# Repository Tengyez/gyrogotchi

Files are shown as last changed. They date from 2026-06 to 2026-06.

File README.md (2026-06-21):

# Gyrogotchi

A tamagotchi that reacts when you flip them in a 4x4 cube keychain using xiao esp32 s3 and mpu6050.

## Description

This is a tamagotchi keychain that introduce another way to interact with the chracter using a gyroscope to be able to tilt the character to triger different animation and around like having a small hamster in a keychain. I wanted to create this because I got inspired by those old 2000 toys where there's innovation and new idea and everythings seems fascinating. My goal here is to make a keychain personalized for me and also double as a nametag I did this by adding a secret code that when I hold a button for 1.5 seccond my credit and name would pop up.

## Getting Started

### Usage

* charge from the usbc port
* press the capacitive touch sensor embeded at the left side 
* shake to wake the character up from sleeping and tilt or flip to trigger different animation
* hold 1.5 seccond to trigger my personalized credit
* connect to gyrogotchi captive portal acess point to broad cast message to the screen and synce time

### Assembling

* Print out the 3d parts (body, cap, minicap, cover) please use the 3mf file I beg you
* place the 500mah lipo batterpack in horizontally
* slide down the cover 3d piece to lock the lipo in place
* put the xiao esp32 s3 in make sure it fits into the usbc slot
* cover the xiao esp32 with the 3d printed minicap
* then place in the mpu6050 on to the two poles above
* then put in the oled screen facing the plastic
* add in the pin to the capacitive touch then solder than cut off the excesspart this need to be flushed to the plastic
* then put in the capacitive touch module make sure the touch side is facing the plastic
* then slide in the vibrating module
* the wire them all up and splice some wire (follow the wiring guide below)
* finally slide in the 3d printed cap

### Wiring
* MPU-6050 to Xiao esp32 S3
* VCC | 3V3
* GND | GND 
* SCL | D5 
* SDA | D4 
* OLED to Xiao esp32 S3
* VCC | 3V3 
* GND | GND 
* SCL | D5 
* SDA | D4 
* Touch (TTP223B) to Xiao esp32 S3
* VCC | 3V3 
* GND | GND 
* SIG | D1 
* Vibrator to Xiao esp32 S3
* Plus | D2
* Negative | GND
* LiPo to Xiao esp32 S3
* Plus | BAT+ 
* Negative | BAT- 
* Splice all 3.3v together and add solder and a electrical tape!!!
* Splice all GND together and add solder and a electrical tape!!!
* Refers to the schematic down below for more indepth guide.

### Firmware

* The code is in C++ made for Xiao ESP-32 S3
* The library version might change over time, please recheck it again.
* feel free to edit and change the credit however you want!
* Check out the [Firmware](firmware/Firmware.ino)
## Materials

This is the BOM of the entire project, just buy the normal one not the pcb version and just use jumper wire with minimal soldering required except for slicing GND together.
```
* Xiao esp32 S3                      1pcs.        20usd
* MPU-6050                           1pcs.        3usd
* 0.96" Inch I2C IIC OLED            1pcs.        3usd
* Touch (TTP223B)                    1pcs.        1usd
* Vibration Motor Module (Catalex)   1pcs.        1usd
* Female Jumper Wires                20pcs.       1usd
* Male Jumper wires                  15pcs.       50cent
* Electrical tape                    1roll        -
* Lipo Battery                       500mah       10usd
* PLA 3d printing/time               ≈25g ≈50min  -
Total cost: 39.5usd
```

## Assembled Pictures


## Rendered Pictures



## Captive Portal interface


## Schematic 


# Zine Poster
GYRO-GOTCHI

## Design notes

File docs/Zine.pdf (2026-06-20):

## GYRO-GOTCHI

# by Teng 15y Play it!

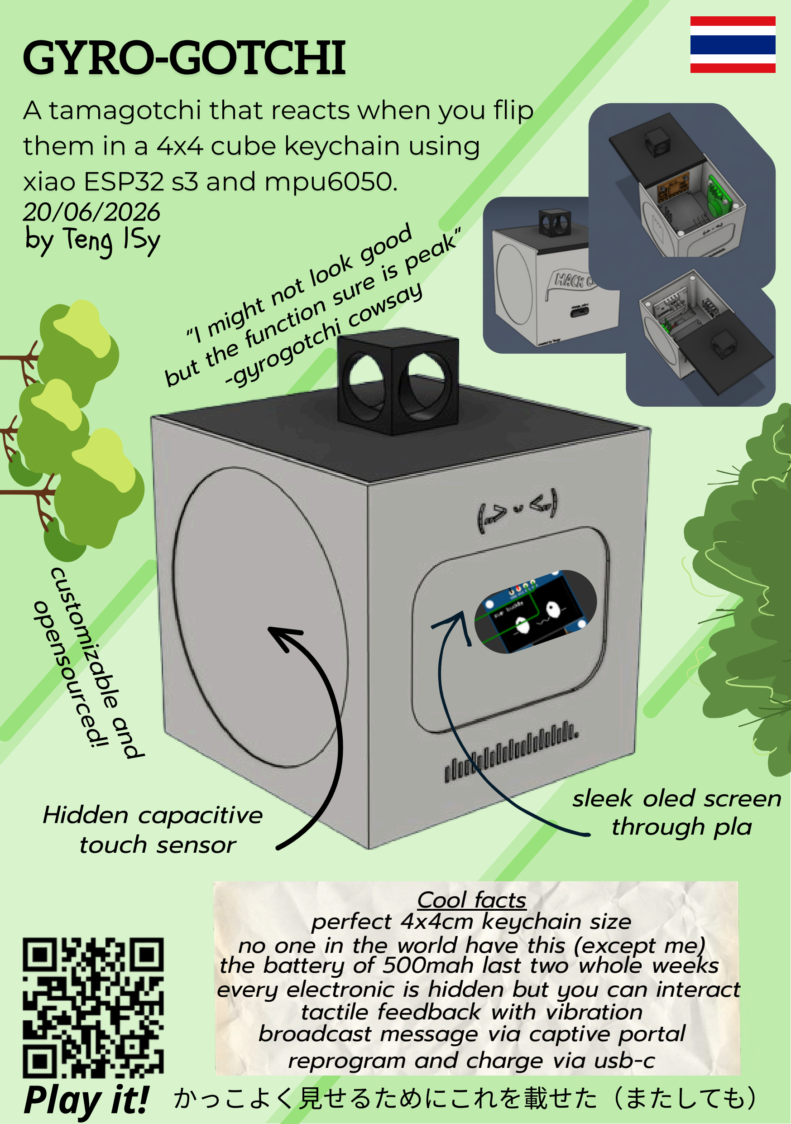
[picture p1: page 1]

A tamagotchi that reacts when you flip them in a 4x4 cube keychain using xiao ESP32 s3 and mpu6050.

A tamagotchi that reacts when you ip them in a 4x4 cube keychain using xiao ESP32 s3 and mpu6050. 20/06/2026

Hidden capacitive
touch sensor

sleek oled screen
through pla

“I might not look good
but the function sure is peak” -gyrogotchi cowsay
かっこよく | 見せるためにこれを載せた（またしても）

perfect 4x4cm keychain size
no one in the world have this (except me)
the battery of 500mah last two whole weeks every electronic is hidden but you can interact tactile feedback with vibration broadcast message via captive portal reprogram and charge via usb-c

Cool facts

customizable

and

opensourced!

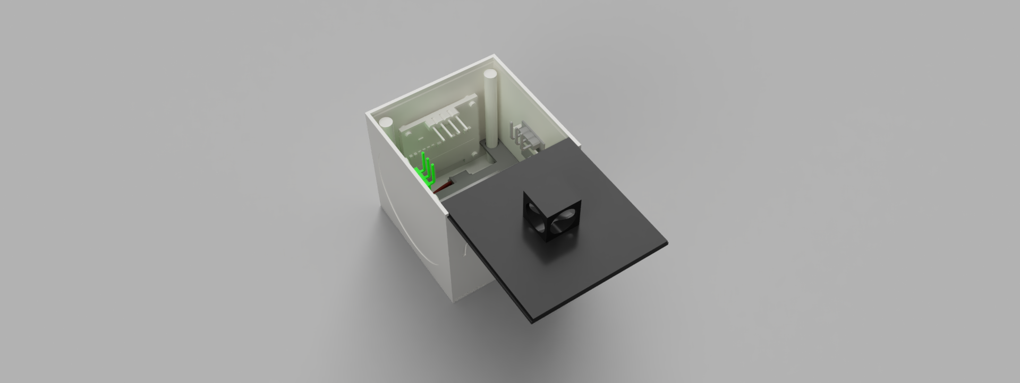
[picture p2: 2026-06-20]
docs/model_pictures/rendered back open.png

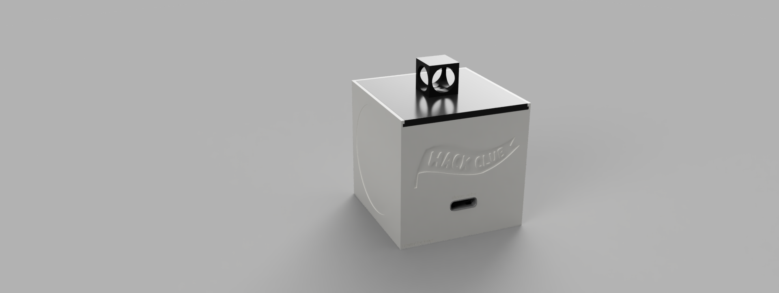
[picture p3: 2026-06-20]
docs/model_pictures/rendered back closed.PNG

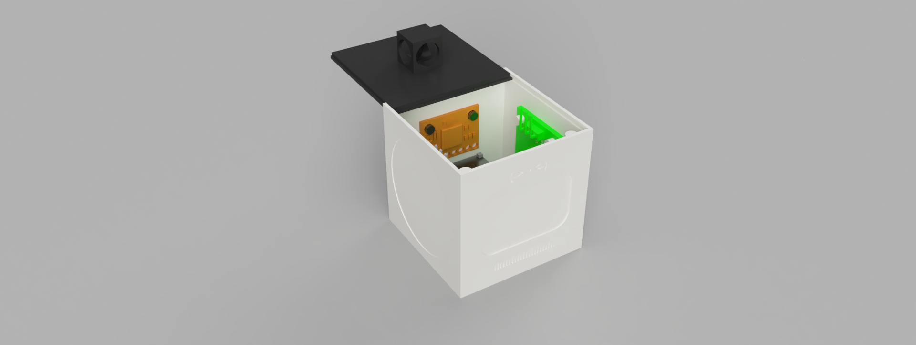
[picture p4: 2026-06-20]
docs/model_pictures/render front open.PNG

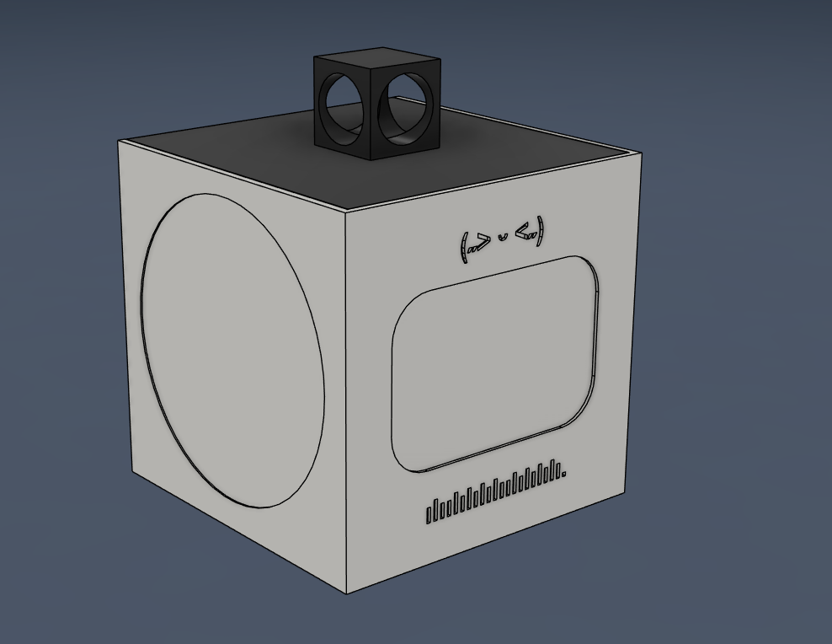
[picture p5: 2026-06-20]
docs/model_pictures/closed.png

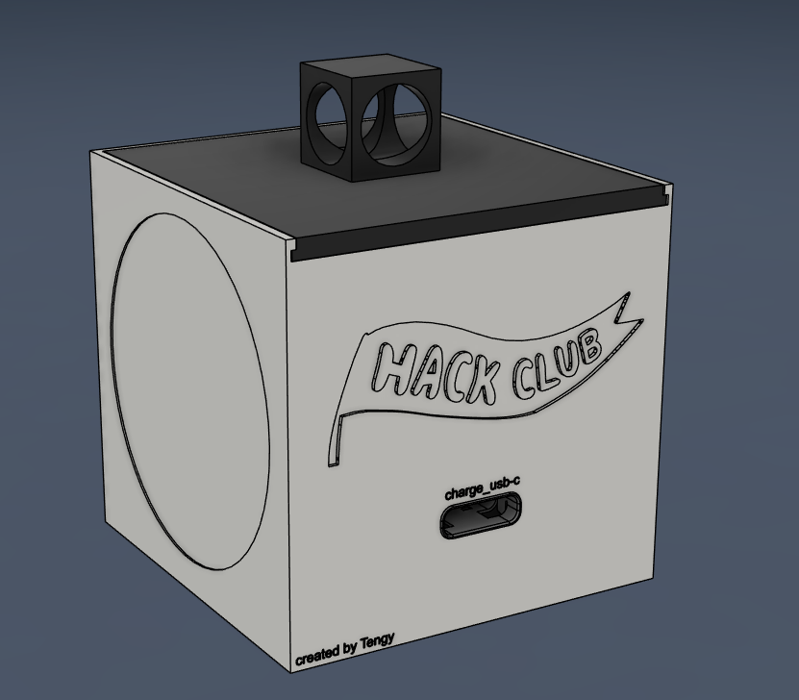
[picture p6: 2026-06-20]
docs/model_pictures/back.png

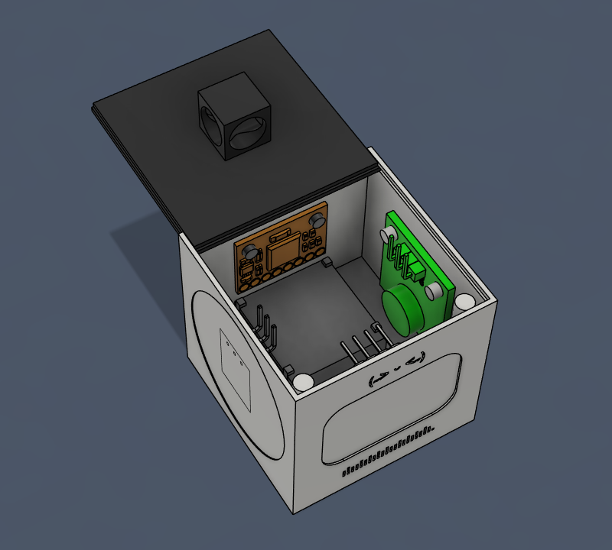
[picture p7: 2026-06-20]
docs/model_pictures/front mini open.png

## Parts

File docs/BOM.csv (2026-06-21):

Components | quantity | comments | link | cost
Xiao esp32 s3 | 1pcs | The small one with no pins | https://www.ortech-online.com/product/5609/xiao-esp32-s3-seeed-studio-%E0%B8%9A%E0%B8%AD%E0%B8%A3%E0%B9%8C%E0%B8%94-esp32-s3-%E0%B8%82%E0%B8%99%E0%B8%B2%E0%B8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 | 20usd
Mpu-6050 | 1pcs | no pins | https://www.ortech-online.com/product/6414/mpu-6050-n-%E0%B9%81%E0%B8%9A%E0%B8%9A%E0%B9%84%E0%B8%A1%E0%B9%88%E0%B8%9A%E0%B8%B1%E0%B8%94%E0%B8%81%E0%B8%A3%E0%B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 | 3usd
0.96" Inch I2C IIC OLED | 1pcs | blue one | https://www.ortech-online.com/product/623/1%E0%B8%8A%E0%B8%B4%E0%B9%89%E0%B8%99-aa412-%E0%B8%AB%E0%B8%99%E0%B9%89%E0%B8%B2%E0%B8%88%E0%B8%AD-%E0%B8%88%E0%B8%A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 | 3usd
touch ttp223b | 1pcs | - | https://www.arduino4pro.com/product/1234/ttp223b-digital-touch-sensor | 1usd
Vibration motor module | 1pcs | catalex | https://www.allnewstep.com/product/1346/%E0%B9%82%E0%B8%A1%E0%B8%94%E0%B8%B9%E0%B8%A5%E0%B8%A1%E0%B8%AD%E0%B9%80%E0%B8%95%E0%B8%AD%E0%B8%A3%E0%B9%8C%E0%B8%AA%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 | 1usd
female jumper wires | 20pcs | any | - | 1usd
male jumper wires | 15pcs | any | - | 50cent
electrical tape | 1roll | any | - | -
lipo battery | 1pcs | 500mah | https://shopee.co.th/%E0%B9%81%E0%B8%9A%E0%B8%95%E0%B9%80%E0%B8%95%E0%B8%AD%E0%B8%A3%E0%B8%B5%E0%B9%88-500mAh-403040-3.7v-Battery-Lipo-polymer-lithium-recharg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 | 10usd
pla | 25g | 50min | - | -
Total cost | 39.5usd | - | - | -

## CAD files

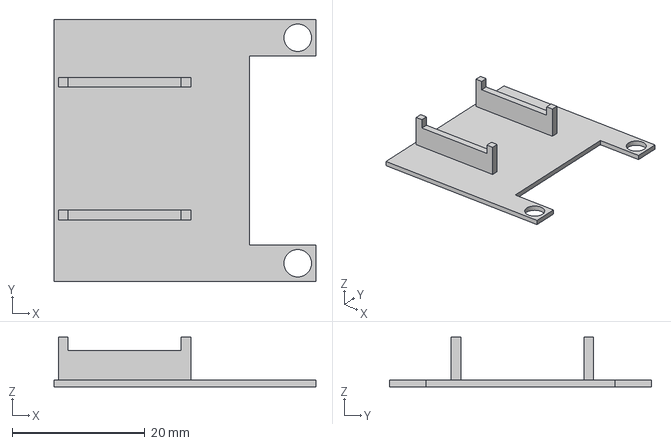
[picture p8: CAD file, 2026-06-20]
3d_print/cover.3mf
39.5 x 39.5 x 7.47 mm

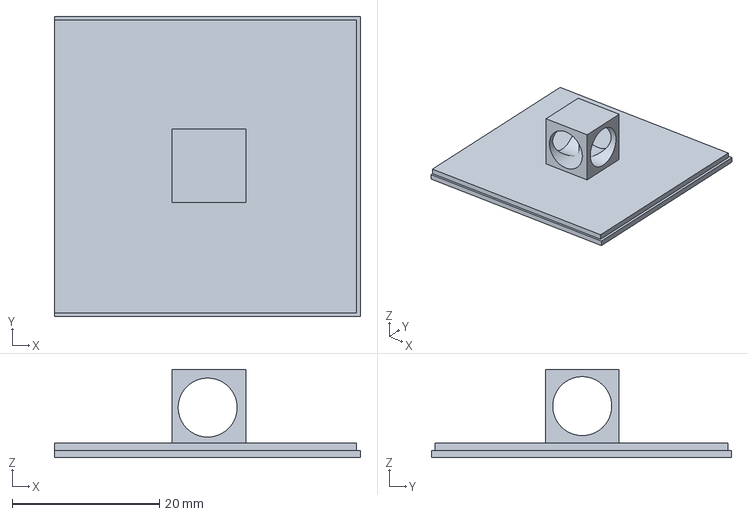
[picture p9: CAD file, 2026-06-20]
3d_print/cap.3mf
41.5 x 40.7 x 12.0 mm

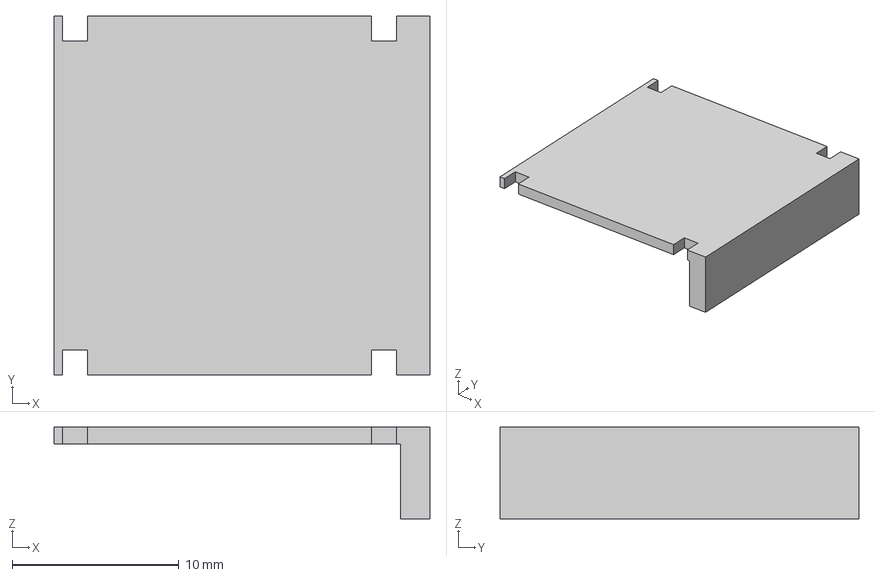
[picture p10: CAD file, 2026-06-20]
3d_print/minicap.3mf
22.5 x 21.5 x 5.50 mm

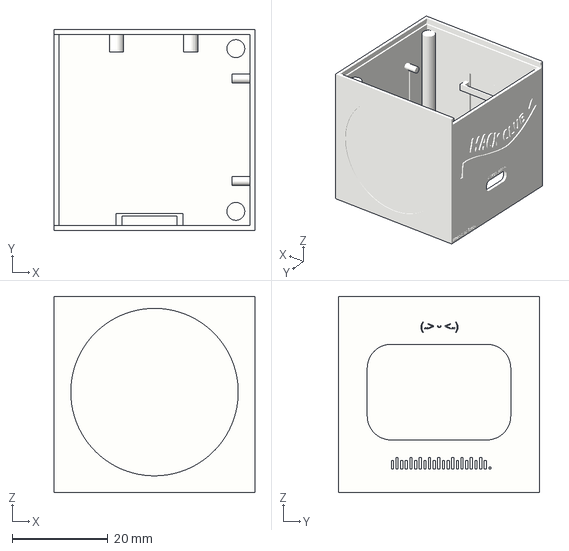
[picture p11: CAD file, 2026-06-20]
3d_print/body.3mf
42.0 x 42.0 x 41.0 mm

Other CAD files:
3d_print/body.stl
3d_print/cap.stl
3d_print/cover.stl
3d_print/minicap.stl

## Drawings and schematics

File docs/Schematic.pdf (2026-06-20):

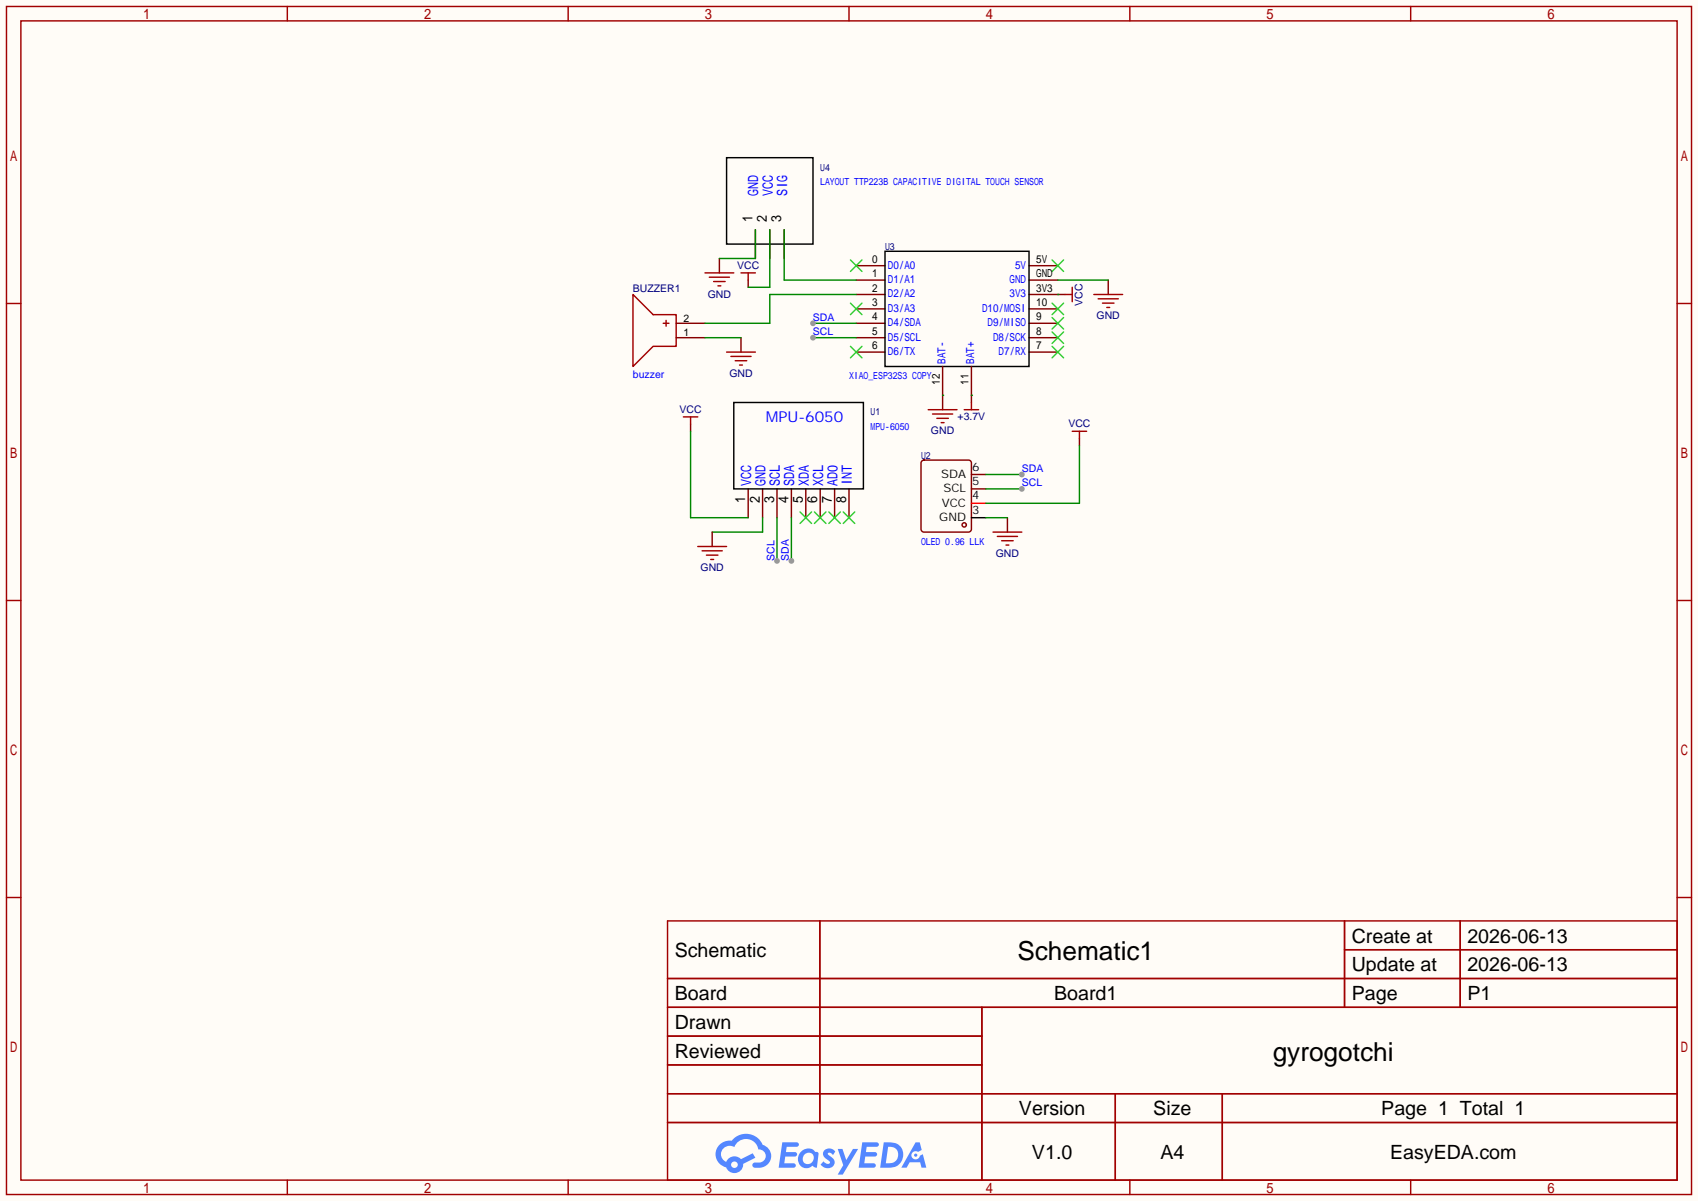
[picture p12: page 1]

LAYOUT TTP223B CAPACITIVE DIGITAL TOUCH SENSOR

Schematic | Schematic1 | Create at | 2026-06-13

Update at | 2026-06-13

Board | Board1 | Page | P1
Drawn | | gyrogotchi
Reviewed

Version | Size | Page 1 Total 1
V1.0 | A4 | EasyEDA.com

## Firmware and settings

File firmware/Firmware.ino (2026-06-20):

#include <Wire.h>
#include <Adafruit_GFX.h>
#include <Adafruit_SSD1306.h>
#include <Adafruit_MPU6050.h>
#include <Adafruit_Sensor.h>
#include <WiFi.h>
#include <DNSServer.h>
#include <WebServer.h>
#include <time.h>

#define TOUCH_PIN      1
#define VIBRATOR_PIN   2

#define SCREEN_WIDTH 128
#define SCREEN_HEIGHT 64
#define OLED_RESET    -1

Adafruit_SSD1306 display(SCREEN_WIDTH, SCREEN_HEIGHT, &Wire, OLED_RESET);
Adafruit_MPU6050 mpu;

WebServer server(80);
DNSServer dnsServer;
const byte DNS_PORT = 53;

int blink_counter = 0;
int zzz_counter = 0;
bool is_sleeping = true; 

unsigned long last_interaction_time = 0;
const unsigned long SLEEP_TIMEOUT = 45000;

unsigned long touch_start_time = 0;
bool touch_was_active = false;
bool showing_credits = false;

String cowsay_text = "";
unsigned long custom_text_display_expiry = 0;

RTC_DATA_ATTR bool has_time_synced = false;
RTC_DATA_ATTR unsigned long rtc_sync_time = 0;
RTC_DATA_ATTR unsigned long rtc_sync_millis = 0;

bool wifi_active = false;
unsigned long wifi_start_millis = 0;
const unsigned long WIFI_PORTAL_TIMEOUT = 60000;

int getBatteryPercentage() {
  pinMode(14, OUTPUT);
  digitalWrite(14, LOW);
  
  int raw = analogRead(10);
  float voltage = (raw / 4096.0) * 3.3 * 2.0; 

  int percent = map(voltage * 100, 330, 420, 0, 100);
  return constrain(percent, 0, 100);
}

String getOrientationString(float x, float y) {
  if (y < -4.0) return "Upside Down";
  if (x < -4.0) return "Tilting Left";
  if (x > 4.0)  return "Tilting Right";
  return "Flat / Centered";
}

unsigned long getCalculatedEpoch() {
  if (!has_time_synced) return 0;
  return rtc_sync_time + ((millis() - rtc_sync_millis) / 1000);
}

void goToDeepSleep() {
  if (wifi_active) {
    WiFi.softAPdisconnect(true);
    WiFi.mode(WIFI_OFF);
  }
  display.clearDisplay();
  display.display();
  digitalWrite(VIBRATOR_PIN, LOW);
  
  esp_deep_sleep_enable_ext0_wakeup((gpio_num_t)TOUCH_PIN, 1);
  esp_deep_sleep_start();
}

void syncTimeFromParam() {
  if (server.hasArg("epoch")) {
    long long epoch = atoll(server.arg("epoch").c_str());
    struct timeval tv;
    tv.tv_sec = epoch;
    tv.tv_usec = 0;
    settimeofday(&tv, NULL);
    rtc_sync_time = epoch;
    rtc_sync_millis = millis();
    has_time_synced = true;
  }
}

void handleRoot() {
  last_interaction_time = millis();
  syncTimeFromParam();
  
  sensors_event_t a, g, t;
  mpu.getEvent(&a, &g, &t);
  
  String html = "<!DOCTYPE html><html><head><meta name='viewport' content='width=device-width, initial-scale=1.0'>";
  html += "<style>body{background:#0f141c;color:#00ffcc;font-family:monospace;text-align:center;padding:20px;}";
  html += ".card{background:#161f2e;border:2px solid #00ffcc;border-radius:8px;padding:15px;margin:15px auto;max-width:400px;box-shadow:0 4px 10px rgba(0,255,204,0.2);}";
  html += "input[type='text']{width:80%;padding:10px;background:#0f141c;border:1px solid #00ffcc;color:#fff;font-family:monospace;margin-bottom:10px;}";
  html += "input[type='submit']{background:#00ffcc;color:#0f141c;border:none;padding:10px 20px;font-weight:bold;cursor:pointer;}";
  html += "</style><script>";
  html += "function syncAndPost(form) {";
  html += "  document.getElementById('deviceTime').value = Math.floor(Date.now() / 1000);";
  html += "  return true;";
  html += "}";
  html += "window.onload = function() {";
  html += "  var xhr = new XMLHttpRequest();";
  html += "  xhr.open('GET', '/sync?epoch=' + Math.floor(Date.now() / 1000), true);";
  html += "  xhr.send();";
  html += "};";
  html += "</script></head><body>";
  html += "<h1>TAMACUBE DASHBOARD</h1>";
  
  html += "<div class='card'>";
  html += "<h3>SYSTEM TELEMETRY</h3>";
  html += "<p><b>Battery Level:</b> " + String(getBatteryPercentage()) + "%</p>";
  html += "<p><b>Orientation:</b> " + getOrientationString(a.acceleration.x, a.acceleration.y) + "</p>";
  
  unsigned long current_epoch = getCalculatedEpoch();
  if(current_epoch > 0) {
    time_t now = (time_t)current_epoch;
    struct tm* timeinfo = localtime(&now);
    char timeStr[20];
    strftime(timeStr, sizeof(timeStr), "%Y-%m-%d %H:%M:%S", timeinfo);
    html += "<p><b>Synced Time:</b> " + String(timeStr) + "</p>";
  } else {
    html += "<p><b>Synced Time:</b> Not Synchronized</p>";
  }
  html += "</div>";

  html += "<div class='card'>";
  html += "<h3>COWSAY TRANSMITTER</h3>";
  html += "<form action='/msg' method='POST' onsubmit='return syncAndPost(this);'>";
  html += "<input type='hidden' id='deviceTime' name='epoch'>";
  html += "<input type='text' name='cowsay' placeholder='Type temporary alert message...' maxlength='32'><br>";
  html += "<input type='submit' value='TRANSMIT TO CUBE'>";
  html += "</form></div>";
  html += "</body></html>";
  server.send(200, "text/html", html);
}

void handleMessage() {
  last_interaction_time = millis(); 
  syncTimeFromParam();
  if (server.hasArg("cowsay")) {
    cowsay_text = server.arg("cowsay");
    custom_text_display_expiry = millis() + 15000;
  }
  server.sendHeader("Location", "/", true);
  server.send(302, "text/plain", "");
}

void handleSync() {
  syncTimeFromParam();
  server.send(200, "text/plain", "OK");
}

void handleCaptiveProbe() {
  server.sendHeader("Location", "http://192.168.4.1/", true);
  server.send(302, "text/plain", "");
}

void setup() {
  Serial.begin(115200);
  pinMode(VIBRATOR_PIN, OUTPUT);
  pinMode(TOUCH_PIN, INPUT);
  
  Wire.begin(4, 5); 

  display.begin(SSD1306_SWITCHCAPVCC, 0x3C);
  mpu.begin();
  mpu.setAccelerometerRange(MPU6050_RANGE_8_G); 
  display.clearDisplay();
  
  digitalWrite(VIBRATOR_PIN, HIGH);
  delay(150);
  digitalWrite(VIBRATOR_PIN, LOW);

  esp_sleep_wakeup_cause_t wakeup_reason = esp_sleep_get_wakeup_cause();
  if (wakeup_reason == ESP_SLEEP_WAKEUP_EXT0) {
    WiFi.softAP("Gyro-Gotchi");
    dnsServer.start(DNS_PORT, "*", WiFi.softAPIP()); 
    server.on("/", HTTP_GET, handleRoot);
    server.on("/msg", HTTP_POST, handleMessage);
    server.on("/sync", HTTP_GET, handleSync);
    server.on("/generate_204", HTTP_GET, handleRoot);
    server.on("/fwlink", HTTP_GET, handleRoot);
    server.onNotFound(handleCaptiveProbe); 
    server.begin();
    wifi_active = true;
    wifi_start_millis = millis();
  }

  if (has_time_synced) {
    struct timeval tv;
    tv.tv_sec = rtc_sync_time + ((millis() - rtc_sync_millis) / 1000);
    tv.tv_usec = 0;
    settimeofday(&tv, NULL);
  }

  last_interaction_time = millis(); 
}

void loop() {
  if (wifi_active) {
    if (millis() - wifi_start_millis > WIFI_PORTAL_TIMEOUT) {
      WiFi.softAPdisconnect(true);
      WiFi.mode(WIFI_OFF);
      dnsServer.stop();
      server.stop();
      wifi_active = false;
    } else {
      dnsServer.processNextRequest();
      server.handleClient();
    }
  }

  sensors_event_t accelerometer_data, gyroscope_data, temperature_data;
  mpu.getEvent(&accelerometer_data, &gyroscope_data, &temperature_data);
  
  display.clearDisplay();
  display.setTextSize(1); 
  display.setTextColor(SSD1306_WHITE);

  bool touch_detected = (digitalRead(TOUCH_PIN) == HIGH);
  float total_force = abs(accelerometer_data.acceleration.x) + abs(accelerometer_data.acceleration.y) + abs(accelerometer_data.acceleration.z);

  if (touch_detected) {
    if (!touch_was_active) {
      touch_start_time = millis();
      touch_was_active = true;
    } else if (millis() - touch_start_time > 1500) {
      showing_credits = true;
    }
  } else {
    touch_was_active = false;
    showing_credits = false;
  }

  if (touch_detected) {
    last_interaction_time = millis(); 
  }

  if (millis() - last_interaction_time > SLEEP_TIMEOUT) {
    goToDeepSleep();
  }

  if (showing_credits) {
    display.setCursor(0, 0);
    display.println("--- CREDITS ---");
    display.setCursor(0, 20);
    display.println("Gyro-Gotchi 06/2026");
    display.println("tengy.org/site");
    display.println("@tengy_ez (Teng 2011)");
  }
  else if (millis() < custom_text_display_expiry) {
    display.setCursor(0, 0);
    display.println("< Broadcast Alert >");
    display.setCursor(0, 24);
    display.print(" ");
    display.println(cowsay_text);
    display.drawRect(0, 16, 128, 32, SSD1306_WHITE);
  }
  else if (is_sleeping) {
    digitalWrite(VIBRATOR_PIN, LOW);

    if (touch_detected) {
      is_sleeping = false;
      digitalWrite(VIBRATOR_PIN, HIGH);
      delay(150);
      digitalWrite(VIBRATOR_PIN, LOW);
      last_interaction_time = millis();
      return;
    }

    display.setCursor(0, 0);
    int bat_pct = getBatteryPercentage();
    
    zzz_counter++;
    unsigned long current_epoch = getCalculatedEpoch();
    if(current_epoch > 0) {
      time_t now = (time_t)current_epoch;
      struct tm* timeinfo = localtime(&now);
      if (zzz_counter < 10) {
        display.printf("[%d%%] %02d:%02d Zzz...", bat_pct, timeinfo->tm_hour, timeinfo->tm_min);
      } else if (zzz_counter < 20) {
        display.printf("[%d%%] %02d:%02d zZzZ...", bat_pct, timeinfo->tm_hour, timeinfo->tm_min);
      } else {
        zzz_counter = 0;
      }
    } else {
      if (zzz_counter < 10) {
        display.printf("[%d%%] Zzz...", bat_pct);
      } else if (zzz_counter < 20) {
        display.printf("[%d%%] zZzZ...", bat_pct);
      } else {
        zzz_counter = 0;
      }
    }

    display.drawLine(25, 38, 45, 38, SSD1306_WHITE); 
    display.drawLine(85, 38, 105, 38, SSD1306_WHITE); 

    display.drawLine(15, 45, 23, 45, SSD1306_WHITE);
    display.drawLine(105, 45, 113, 45, SSD1306_WHITE);
    
    display.drawLine(58, 48, 70, 48, SSD1306_WHITE);
  }
  else {
    display.setCursor(0, 0);
    if (touch_detected) {
      digitalWrite(VIBRATOR_PIN, LOW); 
      display.println("<3 lolol thaat tickles!");
      
      display.drawLine(25, 43, 35, 33, SSD1306_WHITE);
      display.drawLine(35, 33, 45, 43, SSD1306_WHITE);
      
      display.drawLine(83, 43, 93, 33, SSD1306_WHITE);
      display.drawLine(93, 33, 103, 43, SSD1306_WHITE);
      
      display.drawLine(15, 45, 23, 41, SSD1306_WHITE);
      display.drawLine(15, 49, 23, 45, SSD1306_WHITE);
      display.drawLine(105, 41, 113, 45, SSD1306_WHITE);
      display.drawLine(105, 45, 113, 49, SSD1306_WHITE);
      
      display.drawCircle(64, 46, 5, SSD1306_WHITE);
      blink_counter = 0;
    }
    else if (total_force > 25.0) {
      digitalWrite(VIBRATOR_PIN, HIGH);
      display.println("stopppp it im dizzy!");
      
      display.drawLine(25, 33, 45, 53, SSD1306_WHITE);
      display.drawLine(45, 33, 25, 53, SSD1306_WHITE);
      
      display.drawLine(85, 33, 105, 53, SSD1306_WHITE);
      display.drawLine(105, 33, 85, 53, SSD1306_WHITE);
      
      display.drawLine(54, 55, 74, 55, SSD1306_WHITE);
      blink_counter = 0; 
    }
    else if (accelerometer_data.acceleration.y < -4.0) {
      if (millis() % 400 < 200) {
        digitalWrite(VIBRATOR_PIN, HIGH);
      } else {
        digitalWrite(VIBRATOR_PIN, LOW);
      }
      display.println("ay flip me back right now!....... stupid humans");
      
      display.drawLine(20, 33, 45, 43, SSD1306_WHITE);
      display.drawLine(20, 48, 45, 48, SSD1306_WHITE);
      
      display.drawLine(108, 33, 83, 43, SSD1306_WHITE);
      display.drawLine(108, 48, 83, 48, SSD1306_WHITE);
      
      display.drawCircle(64, 57, 4, SSD1306_WHITE);
      blink_counter = 0; 
    }
    else if (accelerometer_data.acceleration.x < -4.0) {
      digitalWrite(VIBRATOR_PIN, LOW);
      display.println("woahh tilting left......");
      
      display.fillCircle(30, 38, 10, SSD1306_WHITE); 
      display.fillCircle(26, 33, 2, SSD1306_BLACK);
      
      display.fillCircle(88, 38, 10, SSD1306_WHITE);
      display.fillCircle(84, 33, 2, SSD1306_BLACK);
      
      display.drawLine(10, 45, 18, 45, SSD1306_WHITE);
      display.drawLine(100, 45, 108, 45, SSD1306_WHITE);
      
      display.drawLine(53, 48, 59, 44, SSD1306_WHITE);
      display.drawLine(59, 44, 65, 48, SSD1306_WHITE);
      display.drawLine(65, 48, 71, 44, SSD1306_WHITE);
      display.drawLine(71, 44, 77, 48, SSD1306_WHITE);
    }
    else if (accelerometer_data.acceleration.x > 4.0) {
      digitalWrite(VIBRATOR_PIN, LOW);
      display.println("yooooo im tilting right!!??");
      
      display.fillCircle(40, 38, 10, SSD1306_WHITE); 
      display.fillCircle(42, 33, 2, SSD1306_BLACK);
      
      display.fillCircle(98, 38, 10, SSD1306_WHITE);
      display.fillCircle(100, 33, 2, SSD1306_BLACK);
      
      display.drawLine(20, 45, 28, 45, SSD1306_WHITE);
      display.drawLine(110, 45, 118, 45, SSD1306_WHITE);
      
      display.drawLine(63, 48, 69, 44, SSD1306_WHITE);
      display.drawLine(69, 44, 75, 48, SSD1306_WHITE);
      display.drawLine(75, 48, 81, 44, SSD1306_WHITE);
      display.drawLine(81, 44, 87, 48, SSD1306_WHITE);
    }
    else {
      digitalWrite(VIBRATOR_PIN, LOW); 
      display.println("sup buddy");
      
      blink_counter++; 
      if (blink_counter == 28 || blink_counter == 29) {
        display.drawLine(25, 38, 45, 38, SSD1306_WHITE); 
        display.drawLine(85, 38, 105, 38, SSD1306_WHITE); 
      } 
      else if (blink_counter >= 30) {
        blink_counter = 0; 
      } 
      else {
        display.fillCircle(35, 38, 10, SSD1306_WHITE); 
        display.fillCircle(33, 33, 2, SSD1306_BLACK);
        
        display.fillCircle(93, 38, 10, SSD1306_WHITE);
        display.fillCircle(91, 33, 2, SSD1306_BLACK);
      }
      
      display.drawLine(15, 45, 23, 45, SSD1306_WHITE);
      display.drawLine(105, 45, 113, 45, SSD1306_WHITE);
      
      display.drawLine(58, 46, 64, 50, SSD1306_WHITE);
      display.drawLine(64, 50, 70, 46, SSD1306_WHITE);
      display.drawLine(70, 46, 76, 50, SSD1306_WHITE);
      display.drawLine(76, 50, 82, 46, SSD1306_WHITE);
    }
  }

  display.display();
  delay(100);
}

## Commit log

2026-06-20 Rename Body1 (1).stl to cover.stl
    [cover.stl]
2026-06-20 Revise wiring section in README.md
    Updated wiring instructions for various components connected to the Xiao ESP32 S3.
2026-06-20 Create Readme.txt with wiring instructions
    Added wiring instructions for various components connected to Xiao ESP32 S3.
2026-06-20 Rename Untitled spreadsheet - Sheet1 (1).csv to BOM.csv
    [BOM.csv]
2026-06-21 Add prices to materials list in README
    Updated the materials list with prices and total cost.
2026-06-21 Add cost column and update BOM entries
    [BOM.csv]
2026-06-21 Update BOM.csv with new component entries
    [BOM.csv]
